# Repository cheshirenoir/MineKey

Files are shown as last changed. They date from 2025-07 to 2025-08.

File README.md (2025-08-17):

# MineKey
A very silly project to build a "better" keyboard for Modded Minecraft.  

##Prerequisites:
You'll need to include the following libraries. They're availabe from the Arduino Library manager  
https://github.com/lostcaggy/rotary_caggy  
https://github.com/adafruit/Adafruit_BusIO  
https://github.com/adafruit/Adafruit-GFX-Library  
https://github.com/adafruit/Adafruit_SSD1306  
Use the Earlphilhower Raspberry Pi Pico board definition https://github.com/earlephilhower/arduino-pico  

##Installation:
Drag the UF2 file to your Pico and that should be it.  

##Compiling
You'll need to put the contents of the libraries folder in your local libraries folder. It contains a modified version of the original keyboard.h file.  

##Some thanks
Brendan and Michael for putting up with my stupid comments and fumblling.  
lostcaggy - This person deserves kudos! This is the first and only library I have found to handle rotary encoders on the Raspberry Pi Pico properly.  
Earlphilhowe - Your work allowed me to actually finish this project!  
johnwasser in the Arduino forums - Your keyboard mod worked to let me generate raw keys for all my keyboards  

##Latest HW differences
Revised schematic with better pin mappings and a spot for a 128x64 OLED rather than the 128x32 I used in the original proto board.  

##Current Key mappings:
I probably should move these to an external file that you can drag into the Pico, but I don't know how to do that. Someone else can add that functionality :-D  

No modifier implements a Numeric Keypad. Row by row, the keys are:  
> 7, 8, 9, /  
> 4, 5, 6, *  
> 1, 2, 3, -  
> 0, stop, return, +   

With the upper META key held down, you mostly get additional function keys. Row by row, the keys are:  
> F13, F14, F15, F16  
> F17, F18, F19, F20  
> F21, F22, F23, F24  
> KEY_OPEN, KEY_HELP, KEY_PROPS, KEY_FRONT  

With the lower SUPER key held down, you get multimedia keys. Row by row, the keys are:  
> KEY_MEDIA_PLAYPAUSE, KEY_MEDIA_STOPCD, KEY_MEDIA_PREVIOUSSONG, KEY_MEDIA_NEXTSONG  
> KEY_MEDIA_EJECTCD, KEY_MEDIA_WWW, KEY_MEDIA_BACK, KEY_MEDIA_FORWARD  
> KEY_MEDIA_STOP, KEY_MEDIA_FIND, KEY_MEDIA_SCROLLUP, KEY_MEDIA_SCROLLDOWN  
> KEY_MEDIA_EDIT, KEY_MEDIA_COFFEE, KEY_MEDIA_REFRESH, KEY_MEDIA_CALC  

With both SUPER and META held down gets you all sorts of random keys. Many probably won't work. Row by row, the keys are:  
> KEY_KPCOMMA, KEY_YEN, KEY_KATAKANAHIRAGANA, KEY_HENKAN  
> Keypad_A, Keypad_B, Keypad_C, Keypad_D  
> Keypad_E, Keypad_F, Keypad_00, Keypad_000  
> Keypad_XOR, Keypad_@, Keypad_+/-, Keypad_!  

CC-BY-SA

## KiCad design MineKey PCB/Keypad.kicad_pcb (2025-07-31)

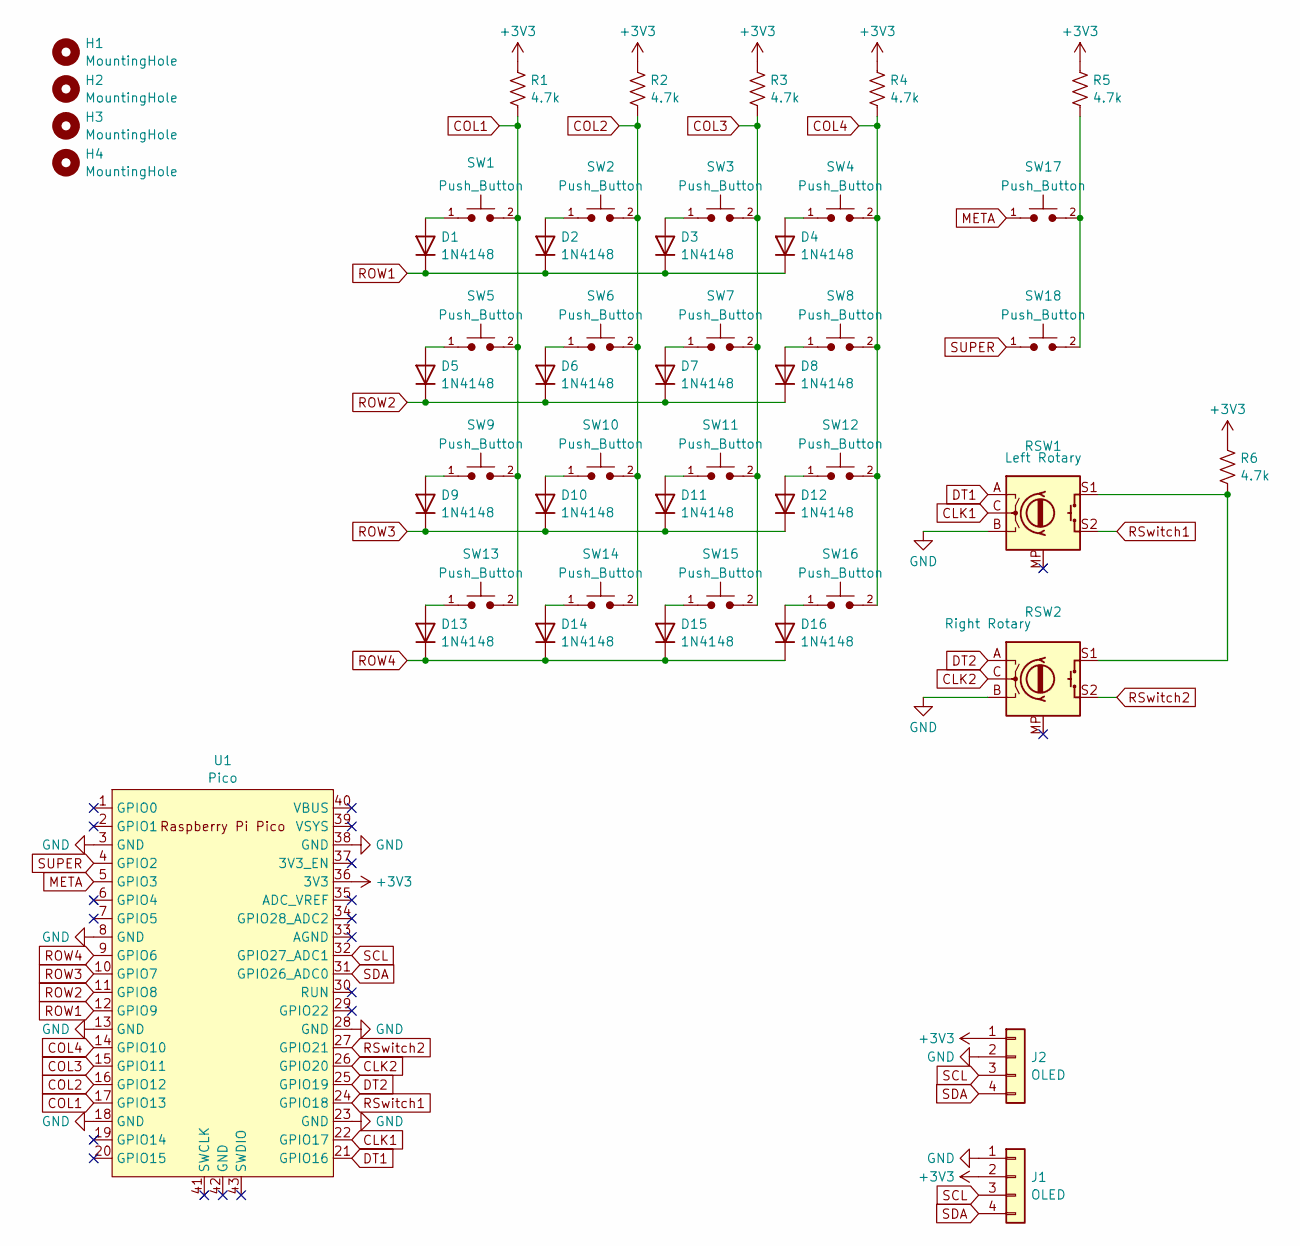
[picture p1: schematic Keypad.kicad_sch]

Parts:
D1, D2, D3, D4, D5, D6, D7, D8, D9, D10, D11, D12, D13, D14, D15, D16: 1N4148; D_5W_P10.16mm_Horizontal
H1, H2, H3, H4: MountingHole; MountingHole_3.2mm_M3
J1, J2: OLED; PinHeader_1x04_P2.54mm_Vertical
R1, R2, R3, R4, R5, R6: 4.7k; R_Axial_DIN0309_L9.0mm_D3.2mm_P12.70mm_Horizontal
RSW1: Left Rotary; RotaryEncoder_Alps_EC12E-Switch_Vertical_H20mm
RSW2: Right Rotary; RotaryEncoder_Alps_EC12E-Switch_Vertical_H20mm
SW1, SW2, SW3, SW4, SW5, SW6, SW7, SW8, SW9, SW10, SW11, SW12, SW13, SW14, SW15, SW16: Push_Button; SW_Cherry_MX_1.00u_PCB
SW17, SW18: Push_Button; SW_Cherry_MX_2.00u_PCB
U1: Pico; RPi_Pico_SMD_TH

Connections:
+3V3: J1.2, J2.1, R1.1, R2.1, R3.1, R4.1, R5.1, R6.1, U1.36 (3V3)
CLK1: RSW1.C, U1.22 (GPIO17)
CLK2: RSW2.C, U1.26 (GPIO20)
COL1: R1.2, SW1.2, SW5.2, SW9.2, SW13.2, U1.17 (GPIO13)
COL2: R2.2, SW2.2, SW6.2, SW10.2, SW14.2, U1.16 (GPIO12)
COL3: R3.2, SW3.2, SW7.2, SW11.2, SW15.2, U1.15 (GPIO11)
COL4: R4.2, SW4.2, SW8.2, SW12.2, SW16.2, U1.14 (GPIO10)
DT1: RSW1.A, U1.21 (GPIO16)
DT2: RSW2.A, U1.25 (GPIO19)
GND: J1.1, J2.2, RSW1.B, RSW2.B, U1.3 (GND), U1.8 (GND), U1.13 (GND), U1.18 (GND), U1.23 (GND), U1.28 (GND), U1.38 (GND)
META: SW17.1, U1.5 (GPIO3)
unnamed: D1.2 (A), SW1.1
unnamed: D2.2 (A), SW2.1
unnamed: D3.2 (A), SW3.1
unnamed: D4.2 (A), SW4.1
unnamed: D5.2 (A), SW5.1
unnamed: D6.2 (A), SW6.1
unnamed: D7.2 (A), SW7.1
unnamed: D8.2 (A), SW8.1
unnamed: D9.2 (A), SW9.1
unnamed: D10.2 (A), SW10.1
unnamed: D11.2 (A), SW11.1
unnamed: D12.2 (A), SW12.1
unnamed: D13.2 (A), SW13.1
unnamed: D14.2 (A), SW14.1
unnamed: D15.2 (A), SW15.1
unnamed: D16.2 (A), SW16.1
unnamed: R5.2, SW17.2, SW18.2
unnamed: R6.2, RSW1.S1, RSW2.S1
ROW1: D1.1 (K), D2.1 (K), D3.1 (K), D4.1 (K), U1.12 (GPIO9)
ROW2: D5.1 (K), D6.1 (K), D7.1 (K), D8.1 (K), U1.11 (GPIO8)
ROW3: D9.1 (K), D10.1 (K), D11.1 (K), D12.1 (K), U1.10 (GPIO7)
ROW4: D13.1 (K), D14.1 (K), D15.1 (K), D16.1 (K), U1.9 (GPIO6)
RSwitch1: RSW1.S2, U1.24 (GPIO18)
RSwitch2: RSW2.S2, U1.27 (GPIO21)
SCL: J1.3, J2.3, U1.32 (GPIO27_ADC1)
SDA: J1.4, J2.4, U1.31 (GPIO26_ADC0)
SUPER: SW18.1, U1.4 (GPIO2)

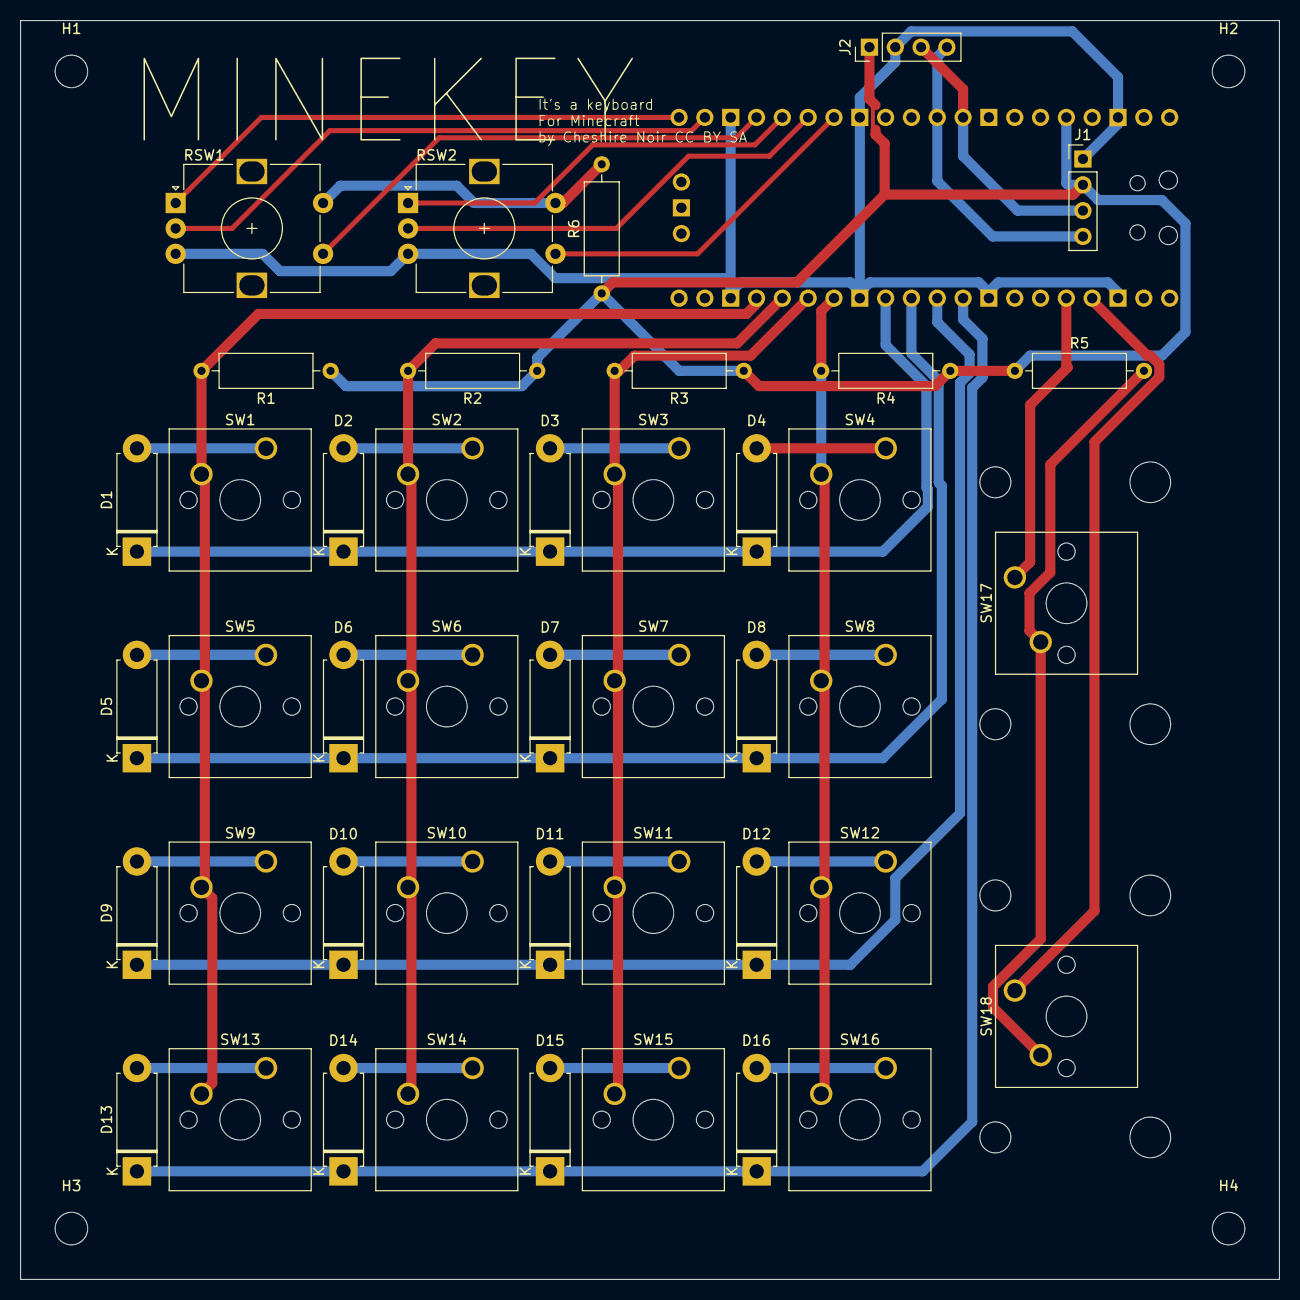
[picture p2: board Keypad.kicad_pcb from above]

Board: 2 copper layers, 123.8 x 123.8 mm, 49 parts (1 on the bottom side), 38 nets.

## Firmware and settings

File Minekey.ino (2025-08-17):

#include <HID_Keyboard.h>
#include <Keyboard.h>
#include <Mouse.h>
#include <Rotary.h>
#include <Wire.h>
#include <Adafruit_GFX.h>
#include <Adafruit_SSD1306.h>

#define SCREEN_WIDTH 128 // OLED display width, in pixels
#define SCREEN_HEIGHT 32 // OLED display height, in pixels
#define MOUSE_SCROLL_AMOUNT 3 //How many lines to scroll the virtual middle mouse on th rotary encoder.

// constants won't change. They're used here to set pin numbers:
const int rowPin1 = 9;        // For row and column scan, row 1 pin
const int rowPin2 = 8;        // For row and column scan, row 2 pin
const int rowPin3 = 7;        // For row and column scan, row 3 pin
const int rowPin4 = 6;        // For row and column scan, row 4 pin

const int colPin1 = 13;       // For row and column scan, column 1 pin
const int colPin2 = 12;       // For row and column scan, column 2 pin
const int colPin3 = 11;       // For row and column scan, column 3 pin
const int colPin4 = 10;       // For row and column scan, column 4 pin

const int buttonPinRL = 18;   // the number of the pushbutton pin
const int buttonPinRR = 21;   // the number of the pushbutton pin
const int buttonPin17 = 3;    // the number of the pushbutton pin
const int buttonPin18 = 2;    // the number of the pushbutton pin

//MICHAEL: Comment out the two lines above and uncmment the two lines below.
//const int buttonPin17 = 1;    // the number of the pushbutton pin
//const int buttonPin18 = 0;    // the number of the pushbutton pin

// Pins for rotary encoder
const int PIN_ROT_A = 16;
const int PIN_ROT_B = 17;
const int PIN_ROT_C = 19;
const int PIN_ROT_D = 20;

//Bitmaps
static const uint8_t image_data_META[512] = {
    0xff, 0xff, 0xff, 0xfe, 0x00, 0x7f, 0xf0, 0x00, 0x00, 0x00, 0x00, 0x00, 0x00, 0x1f, 0xff, 0xff, 
    0xff, 0xff, 0xff, 0xfe, 0x00, 0x7f, 0xe0, 0x08, 0x00, 0x00, 0x00, 0x00, 0x40, 0x1f, 0xff, 0xff, 
    0xff, 0xff, 0xe0, 0xfc, 0x0f, 0x1f, 0xc3, 0xff, 0xff, 0xff, 0xff, 0xff, 0xff, 0x9f, 0xff, 0xff, 
    0xff, 0xef, 0x00, 0xfc, 0x7f, 0x8f, 0x8f, 0xff, 0xff, 0xff, 0xff, 0xff, 0xff, 0xcf, 0xff, 0xff, 
    0xf8, 0x62, 0x02, 0xfc, 0x3f, 0xc7, 0x1f, 0xff, 0xff, 0xff, 0xff, 0xff, 0xff, 0xcf, 0xff, 0xff, 
    0xf0, 0x08, 0xc0, 0xfe, 0x7f, 0xe7, 0x1f, 0xff, 0x07, 0xff, 0x3f, 0xfc, 0x0f, 0xe7, 0xff, 0xff, 
    0xf1, 0x88, 0xe1, 0xfe, 0x7f, 0xe2, 0x3f, 0xe0, 0x00, 0x00, 0x0b, 0xe0, 0x07, 0xe7, 0xff, 0xff, 
    0xf0, 0x03, 0x33, 0xfc, 0x7f, 0xf0, 0x7f, 0xe0, 0x00, 0x00, 0x13, 0xe0, 0xe7, 0xf3, 0xff, 0xff, 
    0xf0, 0x47, 0x9f, 0xfc, 0x7f, 0xf8, 0xff, 0xf3, 0xff, 0xff, 0xfb, 0xe7, 0xe7, 0xf3, 0xff, 0xff, 
    0xf7, 0xc4, 0x00, 0x7c, 0x7f, 0xf8, 0xfd, 0xf3, 0xff, 0xff, 0xf9, 0xe7, 0xef, 0xf1, 0xff, 0xff, 
    0xe7, 0xc0, 0x0f, 0x7e, 0x7f, 0xfc, 0xf8, 0xf3, 0xff, 0xff, 0xf9, 0xe7, 0xef, 0xf9, 0xff, 0xff, 
    0xef, 0x01, 0x8f, 0x8c, 0x79, 0xff, 0xf0, 0xf3, 0xff, 0xff, 0xf9, 0xe7, 0xee, 0x78, 0xff, 0xff, 
    0xee, 0x00, 0x07, 0x04, 0xf8, 0xff, 0xe0, 0xf3, 0xff, 0xff, 0xf9, 0xe7, 0xce, 0x3c, 0xff, 0xff, 
    0xe4, 0x80, 0x03, 0x24, 0xf8, 0x7f, 0xc0, 0xf0, 0x7f, 0xff, 0xf9, 0xe7, 0xce, 0x3c, 0x7f, 0xff, 
    0xf1, 0x80, 0x03, 0x24, 0xf9, 0x3f, 0xc8, 0xe0, 0x3f, 0xff, 0xf9, 0xe7, 0xce, 0x9e, 0x7f, 0xff, 
    0xe3, 0x80, 0x03, 0x04, 0xf9, 0x0f, 0x08, 0xff, 0x1f, 0xff, 0xf9, 0xe7, 0xcc, 0x9e, 0x3f, 0xff, 
    0xe0, 0x80, 0x03, 0x9c, 0xf9, 0xc7, 0x18, 0xff, 0x9f, 0xff, 0xf9, 0xe7, 0x9c, 0x1e, 0x3f, 0xff, 
    0xf0, 0x0c, 0x63, 0xfc, 0xf9, 0xe2, 0x38, 0xfe, 0x1f, 0xff, 0xf9, 0xe7, 0x9c, 0x1f, 0x3f, 0xff, 
    0xfc, 0x00, 0x01, 0xfc, 0xf9, 0xf0, 0x7c, 0xf0, 0x3f, 0xff, 0xf9, 0xe7, 0x9f, 0xff, 0x1f, 0xff, 
    0xfe, 0x01, 0x81, 0xfc, 0xf9, 0xf8, 0xfc, 0xf1, 0xbf, 0xff, 0xf9, 0xe7, 0xbf, 0xff, 0x9f, 0xff, 
    0xf8, 0x00, 0xcb, 0xfc, 0xf9, 0xfc, 0xfc, 0xf3, 0xff, 0xff, 0xf9, 0xe7, 0x3f, 0xcf, 0x9f, 0xff, 
    0xf8, 0x2f, 0x9b, 0xfc, 0xf9, 0xff, 0xfc, 0xf3, 0xff, 0xff, 0xf9, 0xe7, 0x3c, 0x07, 0x8f, 0xff, 
    0xf1, 0x2e, 0x10, 0xfc, 0xf9, 0xff, 0xfc, 0xf3, 0xff, 0xff, 0xf9, 0xe7, 0x38, 0x67, 0xcf, 0xff, 
    0xf1, 0x24, 0x00, 0xfc, 0xf9, 0xff, 0xfc, 0xf2, 0x00, 0x01, 0xf9, 0xe6, 0x79, 0xf3, 0xc7, 0xff, 
    0xf0, 0x70, 0x46, 0x7c, 0xf9, 0xff, 0xfc, 0xf0, 0x00, 0x01, 0xf9, 0xe6, 0x79, 0xf1, 0xc7, 0xff, 
    0xf9, 0x01, 0xc2, 0xfc, 0xf9, 0xff, 0xfc, 0xf0, 0x7f, 0xf9, 0xf9, 0xe6, 0x7b, 0xf9, 0xe3, 0xff, 
    0xff, 0xc7, 0xc1, 0xfc, 0xf9, 0xff, 0xfc, 0xff, 0xff, 0xf9, 0xf9, 0xe6, 0x73, 0xfc, 0xf3, 0xff, 
    0xff, 0xff, 0xe3, 0xfc, 0xf9, 0xff, 0xfc, 0xff, 0xff, 0xf9, 0xf1, 0xe6, 0x73, 0xfc, 0x71, 0xff, 
    0xff, 0xff, 0xff, 0xfc, 0xf9, 0xff, 0xfc, 0xff, 0xff, 0xf9, 0xf3, 0xec, 0xf3, 0xfe, 0x39, 0xff, 
    0xff, 0xff, 0xff, 0xf8, 0xf9, 0xff, 0xfc, 0x1f, 0xe0, 0x01, 0xf3, 0x8c, 0xe7, 0xff, 0x38, 0xff, 
    0xff, 0xff, 0xff, 0xf8, 0x01, 0xff, 0xfc, 0x00, 0x00, 0x03, 0xf0, 0x0c, 0x07, 0xff, 0x00, 0xff, 
    0xff, 0xff, 0xff, 0xf8, 0x01, 0xff, 0xfc, 0x00, 0x00, 0x03, 0xf0, 0x04, 0x07, 0xff, 0x03, 0xff
};

static const uint8_t image_data_SUPER[512] = {
    0xff, 0xff, 0xff, 0xff, 0xff, 0xff, 0xff, 0xff, 0xff, 0xff, 0xff, 0xff, 0xff, 0xff, 0xff, 0xff, 
    0xff, 0xf3, 0x03, 0xff, 0xff, 0xff, 0xff, 0xff, 0xff, 0xff, 0xff, 0xff, 0xff, 0xff, 0xff, 0xff, 
    0xff, 0x00, 0x00, 0x3f, 0xff, 0xff, 0xff, 0xff, 0xff, 0xff, 0xff, 0xff, 0xff, 0xff, 0xff, 0xff, 
    0xfc, 0x00, 0x00, 0x1f, 0xff, 0xff, 0xff, 0xff, 0xff, 0xff, 0xff, 0xff, 0xff, 0xff, 0xff, 0xff, 
    0xfc, 0x00, 0x00, 0x0f, 0xff, 0xff, 0xff, 0xff, 0xff, 0xf8, 0x7f, 0xc7, 0x9f, 0xff, 0xff, 0xff, 
    0xf8, 0x0f, 0xfe, 0x43, 0xff, 0xff, 0xff, 0xfc, 0xfc, 0x00, 0x03, 0xc0, 0x0f, 0xff, 0xff, 0xff, 
    0xf0, 0x3f, 0xff, 0xe3, 0xff, 0x00, 0x00, 0x00, 0x00, 0x1f, 0xf8, 0x4c, 0xcf, 0xff, 0xff, 0xff, 
    0xe0, 0x7e, 0x1f, 0xe0, 0x1f, 0x3e, 0x00, 0x00, 0xff, 0x9c, 0x02, 0x0f, 0x9f, 0xff, 0xff, 0xff, 
    0xc0, 0xf8, 0x07, 0xf0, 0x1f, 0x7e, 0x7f, 0xfe, 0x7f, 0x1c, 0xe1, 0xcf, 0x9f, 0xff, 0xff, 0xff, 
    0xc0, 0xf0, 0x01, 0xf0, 0xdf, 0x7e, 0x7f, 0xff, 0x3f, 0x5d, 0xfc, 0xc7, 0x9f, 0xff, 0xff, 0xff, 
    0xc0, 0xf0, 0x00, 0x78, 0x5e, 0x7e, 0xc0, 0x7f, 0xa6, 0x5d, 0xfe, 0xe7, 0x9f, 0xff, 0xff, 0xff, 
    0xe0, 0xf8, 0x00, 0x00, 0x5e, 0x7e, 0xcf, 0x3f, 0x00, 0x5d, 0xf8, 0xe7, 0xbf, 0xff, 0xff, 0xff, 
    0xf0, 0x7f, 0x00, 0x00, 0x9e, 0xfe, 0xdf, 0x7f, 0x1f, 0xdd, 0xe1, 0xc7, 0x3f, 0xff, 0xff, 0xff, 
    0xf8, 0x3f, 0xff, 0xc0, 0x9c, 0xfc, 0xce, 0x7f, 0x43, 0xdc, 0x0f, 0x87, 0x3f, 0xff, 0xff, 0xff, 
    0xf8, 0x1f, 0xff, 0xc1, 0x9c, 0xfc, 0xc0, 0xfe, 0x73, 0xdf, 0x3c, 0x27, 0x3f, 0xff, 0xff, 0xff, 
    0xfc, 0x00, 0xff, 0xc3, 0x9c, 0xfc, 0xff, 0xfc, 0xf3, 0xdf, 0xf8, 0xe6, 0x7f, 0xff, 0xff, 0xff, 
    0xfe, 0x00, 0x0f, 0xc3, 0x99, 0xfd, 0xff, 0xf9, 0xf3, 0x9f, 0xe3, 0xf6, 0x7f, 0xff, 0xff, 0xff, 
    0xff, 0x00, 0x0f, 0x87, 0x93, 0xfd, 0xff, 0xf3, 0x83, 0x98, 0xef, 0xe6, 0x7f, 0xff, 0xff, 0xff, 
    0xff, 0x84, 0x3f, 0x07, 0xc3, 0xf9, 0xff, 0x87, 0x87, 0x98, 0x67, 0xe0, 0x7f, 0xff, 0xff, 0xff, 
    0xff, 0x87, 0xfe, 0x07, 0xff, 0xf9, 0x80, 0x37, 0x3f, 0x19, 0x27, 0xfc, 0xff, 0xff, 0xff, 0xff, 
    0xff, 0xc3, 0xf8, 0x1b, 0xff, 0xfb, 0x81, 0xe7, 0x20, 0x19, 0xb3, 0xe1, 0xff, 0xff, 0xff, 0xff, 
    0xff, 0xf3, 0xe0, 0x3b, 0xff, 0xfb, 0x9f, 0xef, 0x02, 0x19, 0x99, 0xc8, 0x7f, 0xff, 0xff, 0xff, 
    0xff, 0xf1, 0x00, 0x3b, 0xff, 0xf3, 0x9f, 0xef, 0xfe, 0x39, 0xdc, 0xce, 0x7f, 0xff, 0xff, 0xff, 
    0xff, 0xf9, 0x00, 0x7b, 0xff, 0xf7, 0x9f, 0xef, 0xfe, 0x39, 0xcc, 0xde, 0x7f, 0xff, 0xff, 0xff, 
    0xff, 0xfc, 0x00, 0xfb, 0xff, 0xc7, 0x9f, 0xcf, 0xfe, 0x01, 0xe0, 0x40, 0x7f, 0xff, 0xff, 0xff, 
    0xff, 0xfe, 0x01, 0xfd, 0xff, 0x96, 0x1f, 0xc0, 0x0e, 0x01, 0xff, 0xe0, 0xff, 0xff, 0xff, 0xff, 
    0xff, 0xff, 0x03, 0xfc, 0x7e, 0x30, 0x1f, 0xc0, 0x00, 0x7f, 0xff, 0xff, 0xff, 0xff, 0xff, 0xff, 
    0xff, 0xff, 0x07, 0xff, 0x00, 0xff, 0xff, 0xff, 0xff, 0xff, 0xff, 0xff, 0xff, 0xff, 0xff, 0xff, 
    0xff, 0xff, 0x87, 0xff, 0xff, 0xff, 0xff, 0xff, 0xff, 0xff, 0xff, 0xff, 0xff, 0xff, 0xff, 0xff, 
    0xff, 0xff, 0xcf, 0xff, 0xff, 0xff, 0xff, 0xff, 0xff, 0xff, 0xff, 0xff, 0xff, 0xff, 0xff, 0xff, 
    0xff, 0xff, 0xdf, 0xff, 0xff, 0xff, 0xff, 0xff, 0xff, 0xff, 0xff, 0xff, 0xff, 0xff, 0xff, 0xff, 
    0xff, 0xff, 0xff, 0xff, 0xff, 0xff, 0xff, 0xff, 0xff, 0xff, 0xff, 0xff, 0xff, 0xff, 0xff, 0xff
};

static const uint8_t image_data_SNM[512] = {
    0xff, 0xff, 0xff, 0xff, 0xff, 0xff, 0xff, 0xff, 0xff, 0xff, 0xff, 0xff, 0xff, 0xff, 0xfc, 0x7f, 
    0xfe, 0x00, 0x03, 0xff, 0xff, 0xff, 0xff, 0xff, 0xff, 0xff, 0xff, 0xff, 0xff, 0xff, 0xf0, 0x3f, 
    0xfc, 0x00, 0x00, 0xff, 0xff, 0xff, 0xff, 0xff, 0xff, 0xff, 0xff, 0xff, 0xff, 0xff, 0x80, 0x1f, 
    0xf8, 0x00, 0x00, 0x7f, 0xff, 0xff, 0xff, 0xff, 0x9f, 0xfe, 0x00, 0x3f, 0xff, 0xff, 0x00, 0x1f, 
    0xf0, 0x00, 0x00, 0x7f, 0xff, 0xff, 0xff, 0xff, 0x83, 0xf8, 0x00, 0x00, 0x00, 0x0f, 0x01, 0x1f, 
    0xe0, 0x0f, 0xf0, 0x3f, 0xff, 0xff, 0xff, 0xff, 0xb1, 0xf8, 0x3f, 0x00, 0x00, 0x0f, 0x10, 0x07, 
    0xc0, 0x3f, 0xf8, 0x1f, 0xff, 0xff, 0xff, 0xff, 0xb8, 0x73, 0xff, 0xff, 0xff, 0xe7, 0x00, 0x07, 
    0xc0, 0x70, 0x38, 0x0f, 0xff, 0xff, 0xff, 0xff, 0xbc, 0x27, 0x80, 0x03, 0x80, 0x66, 0x00, 0x0f, 
    0x80, 0x60, 0x38, 0x07, 0xff, 0xff, 0xff, 0xff, 0x9f, 0x04, 0x80, 0x01, 0x80, 0x72, 0x00, 0x1f, 
    0x00, 0x60, 0x30, 0x0f, 0xff, 0xff, 0xff, 0xff, 0x9f, 0x8c, 0x9c, 0x19, 0x9e, 0x72, 0x00, 0x0f, 
    0x00, 0x60, 0x30, 0x18, 0x03, 0x00, 0x00, 0x7f, 0x91, 0x8c, 0x9f, 0xf9, 0x9e, 0x78, 0x00, 0x2f, 
    0x80, 0x78, 0x00, 0x30, 0x21, 0x00, 0x00, 0x1f, 0x90, 0xd8, 0x9f, 0xf9, 0x9c, 0xc8, 0x00, 0x0f, 
    0xc0, 0x3f, 0x00, 0x33, 0x3c, 0x7f, 0x8b, 0x8f, 0x90, 0x70, 0x9f, 0xf9, 0xbc, 0x8c, 0x80, 0x0f, 
    0xe0, 0x1f, 0x80, 0x73, 0x3e, 0x73, 0x80, 0xcf, 0x92, 0x70, 0x9f, 0xf9, 0xb9, 0x84, 0xe0, 0x1f, 
    0xe0, 0x07, 0xc0, 0x73, 0x03, 0x20, 0x04, 0xcf, 0xb3, 0x20, 0x83, 0xf9, 0xb9, 0xb4, 0x63, 0xff, 
    0xf0, 0x00, 0xc0, 0xf3, 0x21, 0x80, 0x0e, 0x49, 0x93, 0x04, 0x81, 0xf8, 0xb9, 0x02, 0x7f, 0xff, 
    0xf0, 0x00, 0xc0, 0xf3, 0x2c, 0x87, 0x60, 0x99, 0x93, 0x8c, 0xf9, 0xf8, 0x39, 0x02, 0x7f, 0xff, 
    0xf8, 0x10, 0xc1, 0xf3, 0x21, 0xc6, 0x61, 0x81, 0x93, 0xdc, 0x99, 0xf8, 0x31, 0xfe, 0x7f, 0xff, 
    0xf8, 0x11, 0xc1, 0xe3, 0x33, 0x86, 0x6e, 0x00, 0x13, 0xfc, 0x81, 0xf8, 0x33, 0xfe, 0x3f, 0xff, 
    0xfc, 0x39, 0xc0, 0xe7, 0x3c, 0x00, 0x78, 0x00, 0x13, 0xf8, 0x83, 0xf8, 0x33, 0xff, 0x3f, 0xff, 
    0xfc, 0x3f, 0x80, 0xe7, 0x20, 0x20, 0x78, 0xe0, 0x13, 0xf9, 0x9f, 0xf8, 0x27, 0x03, 0x1f, 0xff, 
    0xfe, 0x3f, 0x04, 0xe7, 0x22, 0x60, 0x7c, 0xf1, 0x93, 0xf9, 0x9f, 0xf9, 0xa6, 0x01, 0x9f, 0xff, 
    0xfe, 0x00, 0x00, 0xe6, 0x66, 0x40, 0x66, 0x71, 0x93, 0xf9, 0x91, 0xc9, 0xa6, 0x79, 0x8f, 0xff, 
    0xff, 0x00, 0x09, 0xc6, 0x64, 0x40, 0x42, 0x39, 0x93, 0xf9, 0x80, 0x09, 0xa4, 0xf8, 0x8f, 0xff, 
    0xff, 0x00, 0x08, 0x0e, 0x64, 0xce, 0x43, 0x3f, 0x93, 0xf9, 0xfe, 0x49, 0x8c, 0xfc, 0x0f, 0xff, 
    0xff, 0x80, 0x0c, 0x1e, 0x64, 0xc0, 0x41, 0x1f, 0x93, 0xf8, 0xff, 0xe8, 0x01, 0xfe, 0x0f, 0xff, 
    0xff, 0xc0, 0x2f, 0xfc, 0xe4, 0xc0, 0x49, 0x8f, 0x93, 0xfc, 0x00, 0x04, 0x01, 0xfe, 0x1f, 0xff, 
    0xff, 0xc0, 0x27, 0xf8, 0x04, 0x7e, 0x4c, 0x8f, 0x83, 0xfc, 0x00, 0x05, 0xff, 0xff, 0xff, 0xff, 
    0xff, 0xe0, 0x73, 0xe0, 0x0c, 0x00, 0x04, 0x0f, 0x83, 0xff, 0xbf, 0xff, 0xff, 0xff, 0xff, 0xff, 
    0xff, 0xe0, 0xf0, 0x01, 0x8e, 0x00, 0x0c, 0x7f, 0xff, 0xff, 0xff, 0xff, 0xff, 0xff, 0xff, 0xff, 
    0xff, 0xf8, 0xfc, 0x3f, 0xfe, 0x7e, 0xff, 0xff, 0xff, 0xff, 0xff, 0xff, 0xff, 0xff, 0xff, 0xff, 
    0xff, 0xfd, 0xff, 0xff, 0xff, 0xff, 0xff, 0xff, 0xff, 0xff, 0xff, 0xff, 0xff, 0xff, 0xff, 0xff
};

//Mapping into an array of all 16 keys so they can be swapped out easily
//Order is SW1-SW16
//These are the raw keymappings as sent to the HID output.
char keycharmap[4][16] = {
  {0x5f,0x60,0x61,0x54,0x5c,0x5d,0x5e,0x55,0x59,0x5a,0x5b,0x56,0x62,0x63,0x58,0x57},
  {0x68,0x69,0x6a,0x6b,0x6c,0x6d,0x6e,0x6f,0x70,0x71,0x72,0x73,0x74,0x75,0x76,0x77},
  {0xe8,0xe9,0xea,0xeb,0xec,0xef,0xf0,0xf1,0xf2,0xf3,0xf4,0xf5,0xf6,0xf7,0xf9,0xfb},
  {0x85,0x89,0x88,0x8a,0xbc,0xbd,0xbe,0xbf,0xc0,0xc1,0xb0,0xb1,0xc2,0xce,0xd7,0xcf}
};
//Row one is Numeric Keypad 7,8,9,/,4,5,6,*,1,2,3,-,0,stop,return,+
//Row two is Additional Function keys F13,F14,F15,F16,F17,F18,F19,F20,F21,F22,F23,F24,KEY_OPEN,KEY_HELP,KEY_PROPS,KEY_FRONT
//Row three is multimedia keys KEY_MEDIA_PLAYPAUSE,KEY_MEDIA_STOPCD,KEY_MEDIA_PREVIOUSSONG,KEY_MEDIA_NEXTSONG,KEY_MEDIA_EJECTCD,KEY_MEDIA_WWW,KEY_MEDIA_BACK,KEY_MEDIA_FORWARD,KEY_MEDIA_STOP,KEY_MEDIA_FIND,KEY_MEDIA_SCROLLUP,KEY_MEDIA_SCROLLDOWN,KEY_MEDIA_EDIT,KEY_MEDIA_COFFEE,KEY_MEDIA_REFRESH,KEY_MEDIA_CALC
//Row four is all sorts of random keys. Many probably won't work. KEY_KPCOMMA,KEY_YEN,KEY_KATAKANAHIRAGANA,KEY_HENKAN,Keypad_A,Keypad_B,Keypad_C,Keypad_D,Keypad_E,Keypad_F,Keypad_00,Keypad_000,Keypad_XOR,Keypad_@,Keypad_+/-,Keypad_!


// Declare the two rotary encoders
Rotary rotaryL = Rotary(PIN_ROT_A, PIN_ROT_B);
Rotary rotaryR = Rotary(PIN_ROT_C, PIN_ROT_D);

// Declaration for an SSD1306 display connected to I2C (SDA, SCL pins)
Adafruit_SSD1306 display(SCREEN_WIDTH, SCREEN_HEIGHT, &Wire1, -1);
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
void loop() {
  // read the state of the Rotary Left switch into a local variable:
  int reading = digitalRead(buttonPinRL);

  // check to see if you just pressed the button
  // (i.e. the input went from LOW to HIGH), and you've waited long enough
  // since the last press to ignore any noise:

  // If the switch changed, due to noise or pressing:
  if (reading != lastButtonStateRL) {
    // reset the debouncing timer
    lastDebounceTimeRL = millis();
  }

  if ((millis() - lastDebounceTimeRL) > debounceDelay) 
  {
    // whatever the reading is at, it's been there for longer than the debounce
    // delay, so take it as the actual current state:

    // if the button state has changed:
    if (reading != buttonStateRL) 
    {
      buttonStateRL = reading;

      // only output the character if the new button state is HIGH, else release the key.
      if (buttonStateRL == HIGH) 
      {
        Keyboard.press(KEY_NUM_LOCK);
      }
      else
      {
	      Keyboard.release(KEY_NUM_LOCK);
      }
    }
  }

  // save the reading. Next time through the loop, it'll be the lastButtonState:
  lastButtonStateRL = reading;

  // Now Rotary Right
  reading = digitalRead(buttonPinRR);

  if (reading != lastButtonStateRR) 
  {
    lastDebounceTimeRR = millis();
  }

  if ((millis() - lastDebounceTimeRR) > debounceDelay) 
  {
    if (reading != buttonStateRR) 
    {
      buttonStateRR = reading;
      if (buttonStateRR == HIGH) 
      {
        Keyboard.consumerPress(KEY_MUTE);
        Keyboard.consumerRelease();
      }
    }
  }

  lastButtonStateRR = reading;

  // Now the META key
  reading = digitalRead(buttonPin17);

  if (reading != lastButtonState17) 
  {
    lastDebounceTime17 = millis();
  }

  if ((millis() - lastDebounceTime17) > debounceDelay) 
  {
    if (reading != buttonState17) 
    {
      buttonState17 = reading;
      if (buttonState17 == HIGH) 
      {
        metasuper=metasuper+1;
      }
      else
      {
	      metasuper=metasuper-1;
      }
    }
  }

  lastButtonState17 = reading;

  // Now the SUPER key
  reading = digitalRead(buttonPin18);

  if (reading != lastButtonState18) 
  {
    lastDebounceTime18 = millis();
  }

  if ((millis() - lastDebounceTime18) > debounceDelay) 
  {
    if (reading != buttonState18) 
    {
      buttonState18 = reading;
      if (buttonState18 == HIGH) 
      {
        metasuper=metasuper+2;
      }
      else
      {
        metasuper=metasuper-2;
      }
    }
  }

  lastButtonState18 = reading;

  // Time to strobe the current column and deal with what pops out
  switch(currentCol)
  {
  case 1:
    // This is the first column. Pull the column pin high to activate it.
    digitalWrite(colPin1, HIGH);
    reading = digitalRead(rowPin1);
    if (reading != lastButtonState1) 
    {
      lastDebounceTime1 = millis();
    }
    if ((millis() - lastDebounceTime1) > debounceDelay) 
    {
      if (reading != buttonState1) 
      {
        buttonState1 = reading;
        if (buttonState1 == HIGH) 
        {
          Keyboard.pressRaw(keycharmap[metasuper][0]);
        }
	else
        {
	        Keyboard.releaseRaw(keycharmap[metasuper][0]);
        }
      }
    }
    lastButtonState1 = reading;

    reading = digitalRead(rowPin2);
    if (reading != lastButtonState5) 
    {
      lastDebounceTime5 = millis();
    }
    if ((millis() - lastDebounceTime5) > debounceDelay) 
    {
      if (reading != buttonState5) 
      {
        buttonState5 = reading;
        if (buttonState5 == HIGH) 
        {
          Keyboard.pressRaw(keycharmap[metasuper][4]);
        }
	else
        {
	        Keyboard.releaseRaw(keycharmap[metasuper][4]);
        }
      }
    } 
    lastButtonState5 = reading;

    reading = digitalRead(rowPin3);
    if (reading != lastButtonState9) 
    {
      lastDebounceTime9= millis();
    }
    if ((millis() - lastDebounceTime9) > debounceDelay) 
    {
      if (reading != buttonState9) 
      {
        buttonState9 = reading;
        if (buttonState9 == HIGH) 
        {
          Keyboard.pressRaw(keycharmap[metasuper][8]);
        }
	else
        {
	        Keyboard.releaseRaw(keycharmap[metasuper][8]);
        }
      }
    }
    lastButtonState9 = reading;
    
    reading = digitalRead(rowPin4);
    if (reading != lastButtonState13) 
    {
      lastDebounceTime13 = millis();
    }
    if ((millis() - lastDebounceTime13) > debounceDelay) 
    {
      if (reading != buttonState13) 
      {
        buttonState13 = reading;
        if (buttonState13 == HIGH) 
        {
          Keyboard.pressRaw(keycharmap[metasuper][12]);
        }
	else
        {
	        Keyboard.releaseRaw(keycharmap[metasuper][12]);
        }
      }
    }
    lastButtonState13 = reading;

    // now pull the pin back dwon.
    digitalWrite(colPin1, LOW);

  case 2:
    // this is column 2
    digitalWrite(colPin2, HIGH);
    reading = digitalRead(rowPin1);
    if (reading != lastButtonState2) 
    {
      lastDebounceTime2 = millis();
    }
    if ((millis() - lastDebounceTime2) > debounceDelay) 
    {
      if (reading != buttonState2) 
      {
        buttonState2 = reading;
        if (buttonState2 == HIGH) 
        {
          Keyboard.pressRaw(keycharmap[metasuper][1]);
        }
	else
        {
	        Keyboard.releaseRaw(keycharmap[metasuper][1]);
        }
      }
    }
    lastButtonState2 = reading;

    reading = digitalRead(rowPin2);
    if (reading != lastButtonState6) 
    {
      lastDebounceTime6 = millis();
    }
    if ((millis() - lastDebounceTime6) > debounceDelay) 
    {
      if (reading != buttonState6) 
      {
        buttonState6 = reading;
        if (buttonState6 == HIGH) 
        {
          Keyboard.pressRaw(keycharmap[metasuper][5]);
        }
	else
        {
	        Keyboard.releaseRaw(keycharmap[metasuper][5]);
        }
      }
    } 
    lastButtonState6 = reading;

    reading = digitalRead(rowPin3);
    if (reading != lastButtonState10) 
    {
      lastDebounceTime10 = millis();
    }
    if ((millis() - lastDebounceTime10) > debounceDelay) 
    {
      if (reading != buttonState10) 
      {
        buttonState10 = reading;
        if (buttonState10 == HIGH) 
        {
          Keyboard.pressRaw(keycharmap[metasuper][9]);
        }
	else
        {
	        Keyboard.releaseRaw(keycharmap[metasuper][9]);
        }
      }
    }
    lastButtonState10 = reading;

    reading = digitalRead(rowPin4);
    if (reading != lastButtonState14) 
    {
      lastDebounceTime8 = millis();
    }
    if ((millis() - lastDebounceTime14) > debounceDelay) 
    {
      if (reading != buttonState14) 
      {
        buttonState14 = reading;
        if (buttonState14 == HIGH) 
        {
          Keyboard.pressRaw(keycharmap[metasuper][13]);
        }
	else
        {
	        Keyboard.releaseRaw(keycharmap[metasuper][13]);
        }
      }
    }
    lastButtonState14 = reading;

    digitalWrite(colPin2, LOW);

  case 3:
    // The third column
    digitalWrite(colPin3, HIGH);
    reading = digitalRead(rowPin1);
    if (reading != lastButtonState3) 
    {
      lastDebounceTime3 = millis();
    }
    if ((millis() - lastDebounceTime3) > debounceDelay) 
    {
      if (reading != buttonState3) 
      {
        buttonState3 = reading;
        if (buttonState3 == HIGH) 
        {
          Keyboard.pressRaw(keycharmap[metasuper][2]);
        }
	else
        {
	        Keyboard.releaseRaw(keycharmap[metasuper][2]);
        }
      }
    }
    lastButtonState3 = reading;

    reading = digitalRead(rowPin2);
    if (reading != lastButtonState7) 
    {
      lastDebounceTime7 = millis();
    }
    if ((millis() - lastDebounceTime7) > debounceDelay) 
    {
      if (reading != buttonState7) 
      {
        buttonState7 = reading;
        if (buttonState7 == HIGH) 
        {
          Keyboard.pressRaw(keycharmap[metasuper][6]);
        }
	else
        {
	        Keyboard.releaseRaw(keycharmap[metasuper][6]);
        }
      }
    } 
    lastButtonState7 = reading;

    reading = digitalRead(rowPin3);
    if (reading != lastButtonState11) 
    {
      lastDebounceTime11 = millis();
    }
    if ((millis() - lastDebounceTime11) > debounceDelay) 
    {
      if (reading != buttonState11) 
      {
        buttonState11 = reading;
        if (buttonState11 == HIGH) 
        {
          Keyboard.pressRaw(keycharmap[metasuper][10]);
        }
	else
        {
	        Keyboard.releaseRaw(keycharmap[metasuper][10]);
        }
      }
    }
    lastButtonState11 = reading;

    reading = digitalRead(rowPin4);
    if (reading != lastButtonState15) 
    {
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

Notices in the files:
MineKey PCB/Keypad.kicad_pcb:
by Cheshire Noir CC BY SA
